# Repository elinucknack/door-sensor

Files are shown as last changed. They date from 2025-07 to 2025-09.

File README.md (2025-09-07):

# Door sensor

This is the documentation of Door sensor, an application that enables to create a door sensor from a Raspberry Pi. This door sensor can work offline or can be connected to an MQTT broker!

The following steps describe the installation of Door sensor on Raspberry Pi.

## Hardware build

The door sensor consists of a Raspberry Pi Zero 2 WH micro computer with additional electronic components allowing the micro computer to control the door sensor. Below, you can see the door sensor circuit schemes (also available in the `.kicad_sch` format):

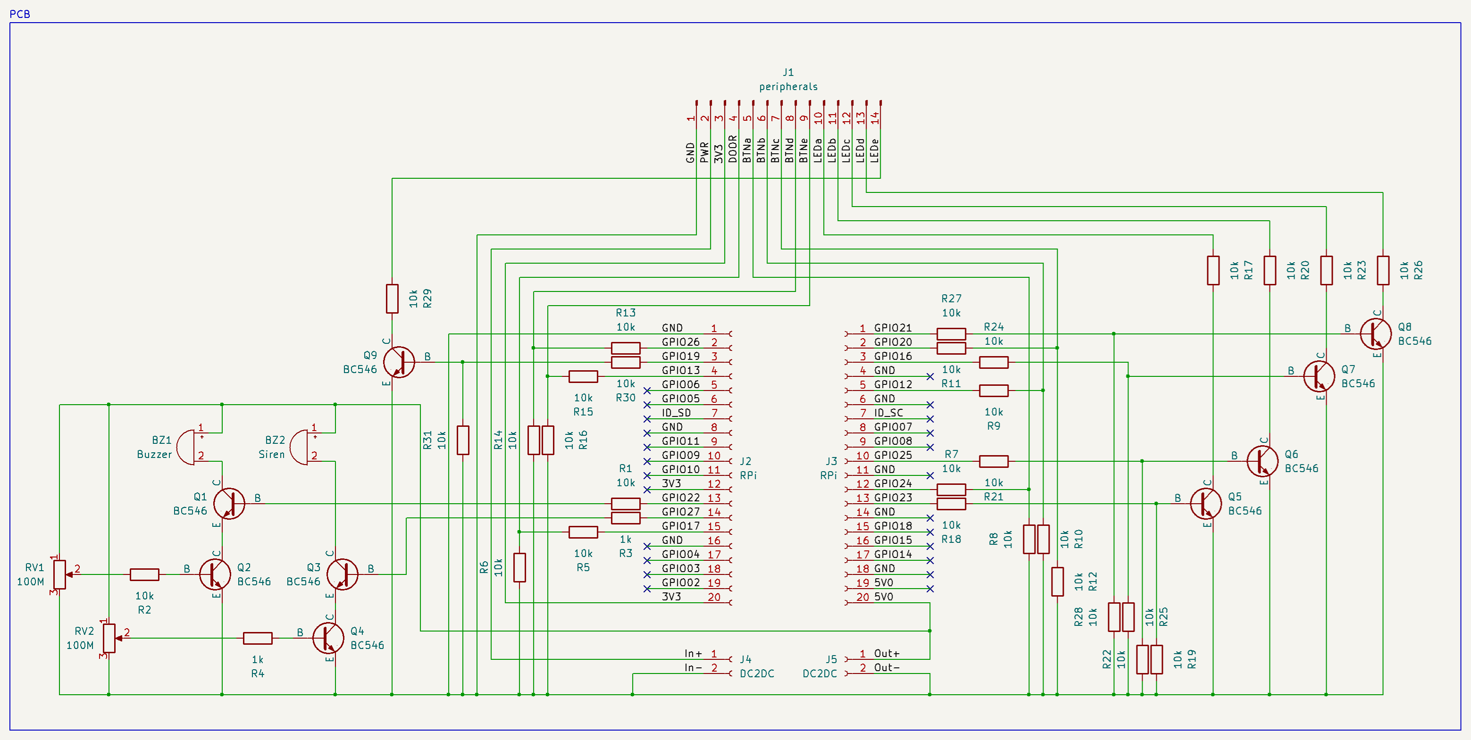
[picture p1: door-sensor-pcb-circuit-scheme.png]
Door sensor PCB circuit scheme


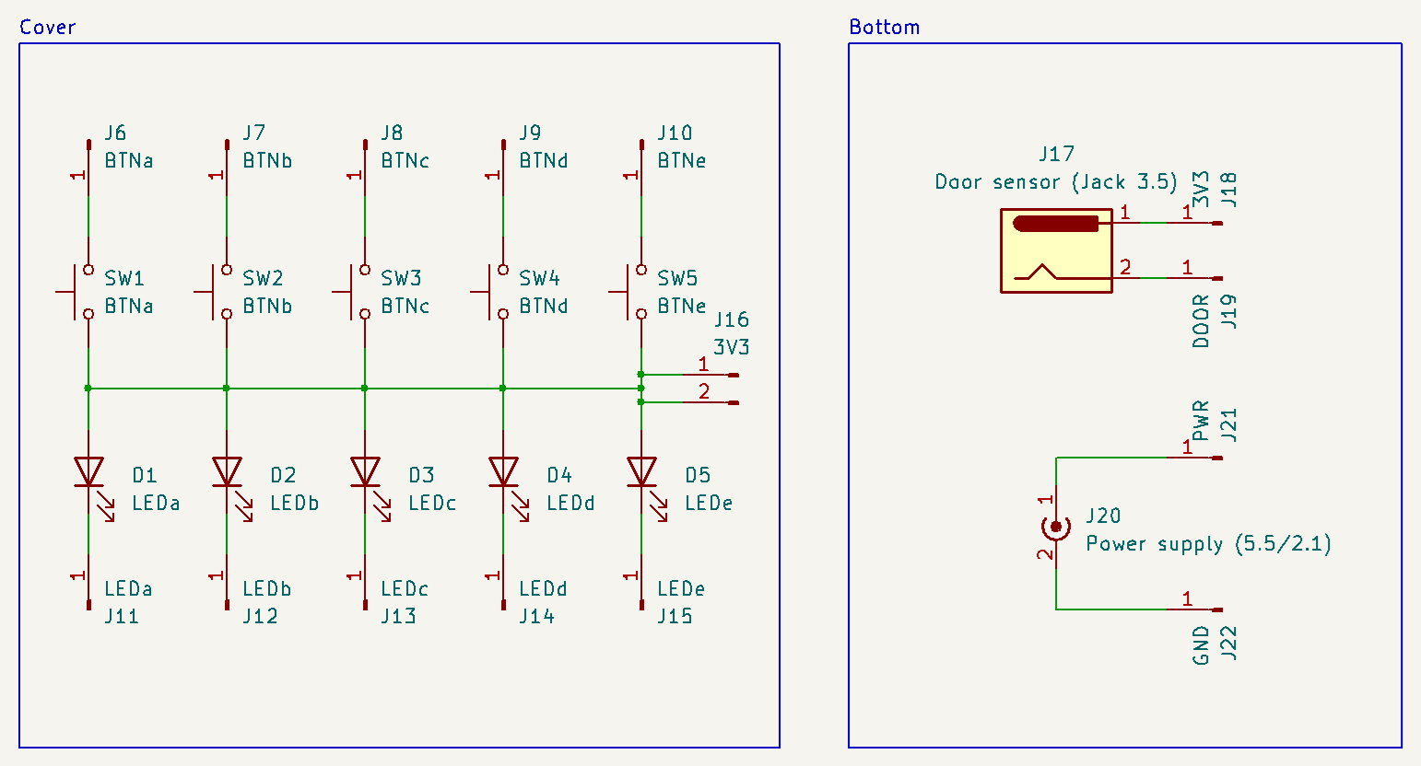
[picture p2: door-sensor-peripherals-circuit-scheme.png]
Door sensor peripherals circuit scheme


Below, you can see both sides of the door sensor PCB design (also available in the `.svg` format, the design uses an universal drilled PCB with 2.54mm hole pitch):

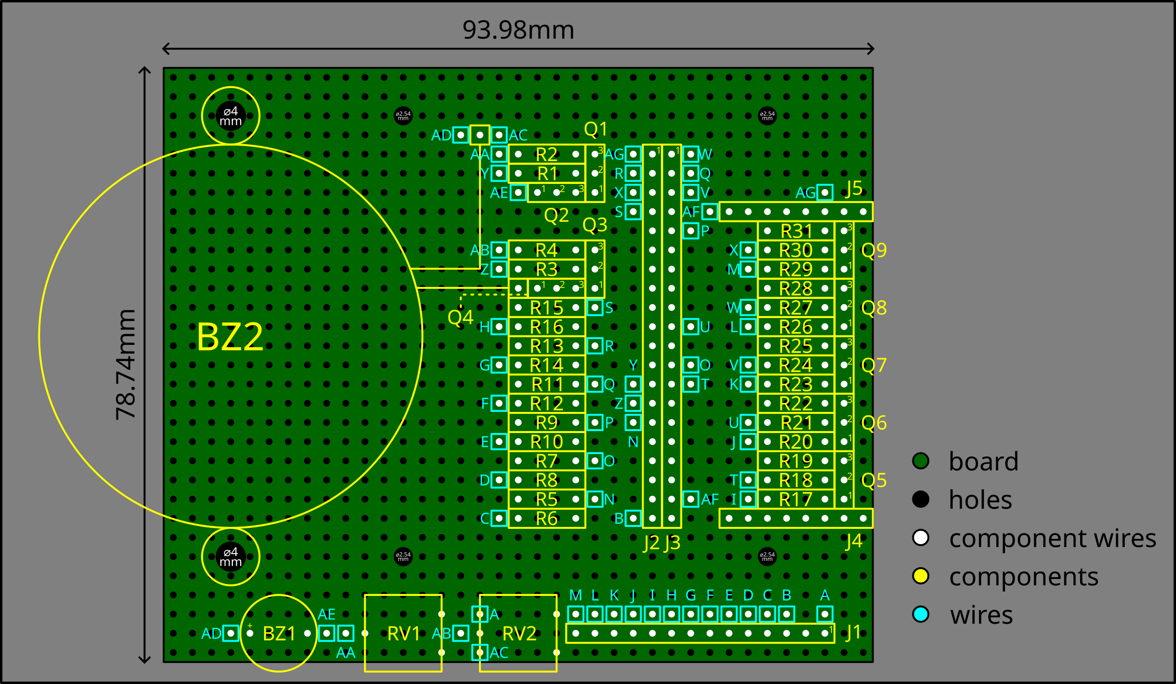
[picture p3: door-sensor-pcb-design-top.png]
PCB design - top side


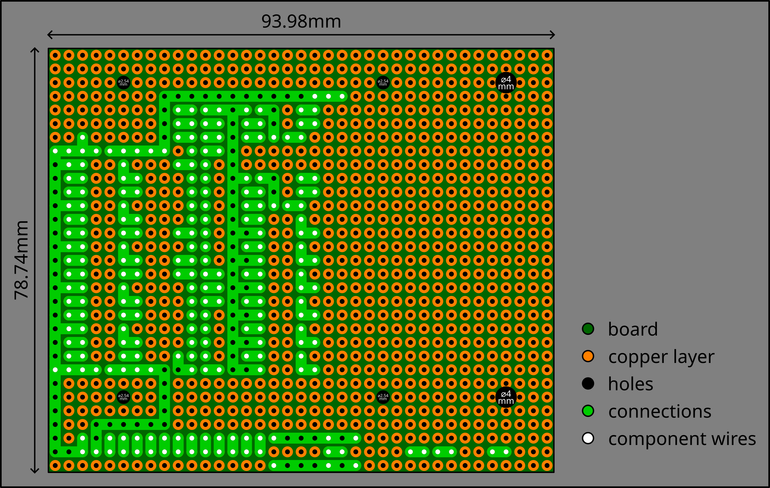
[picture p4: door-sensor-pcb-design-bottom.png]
PCB design - bottom side


The repository also includes printable 3D models (`.stl` files) of cases for the PCB. To mount the PCB to the case, you need 4 2.5×10mm screws. To assembly the case, you need 4 3.5×30mm screws. You also need 1 M4×30mm metric screw and 1 M4 nut in case you want to mount the camera holder. In case you don't want to edit the model, following components are recommended to be used if they are to fit into the holes in the PCB and in the case:
- KPEG242 as the buzzer `BZ1` ([link here](https://www.gmelectronic.com/v/1499434/kingstate-kpeg242-piezobuzzer))
- PS-583Q as the siren `BZ2` ([link here](https://www.gmelectronic.com/v/1498662/hitpoint-ps-583q-piezobuzzer), to mount the siren to the PCB, you need 2 M4×10mm metric screws and 2 M4 nuts)
- CA9VK100 as trimmers `RV1` and `RV2` ([link here](https://www.gmelectronic.com/v/1491831/acp-ca9vk100-carbon-trimmer))
- PBS-11B-R as buttons `SW1`, `SW2`, `SW3`, `SW4` and `SW5` ([link here](https://www.gmelectronic.com/v/1501016/pbs-11b-r-tlacitko-do-panelu-1-pol-offon))
- JC-204 as the Jack 3.5mm connector `J17` ([link here](https://www.gmelectronic.com/v/1497212/ninigi-jc-204-jack-35-mono))
- DS-026B as the power supply connector `J20` ([link here](https://www.gmelectronic.com/v/1498555/ds-026b-dc-connector-55-21))
- L-53LSRD as LEDs ([link here](https://www.gmelectronic.com/v/1491570/kingbright-l-53lsrd-led-5mm-cervena), regarding the required color and brightness, pick correspinding resistors `R17`, `R19`, `R21`, `R23` and `R25`)
- BL-C2 HR04C2 as LED sockets ([link here](https://www.gmelectronic.com/v/1492931/bright-led-bl-c2-hr04c2-objimka-pro-led-5mm))

Below, you can see an example of the built hardware:

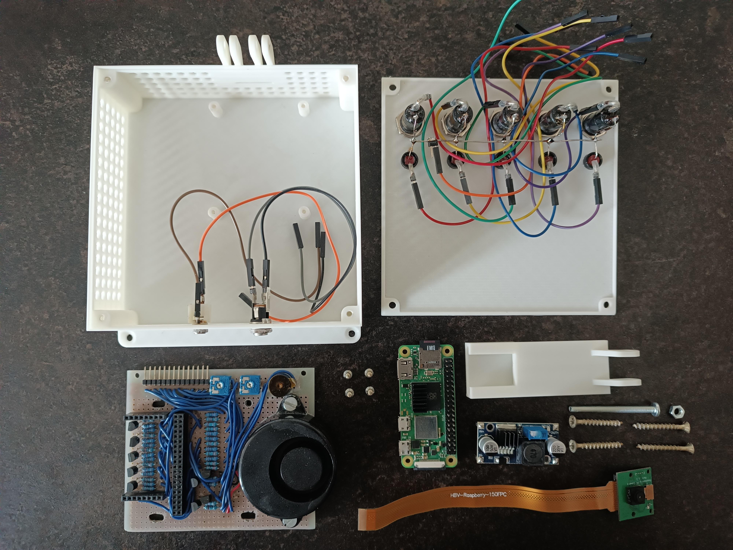
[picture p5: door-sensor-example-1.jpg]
Door sensor example 1


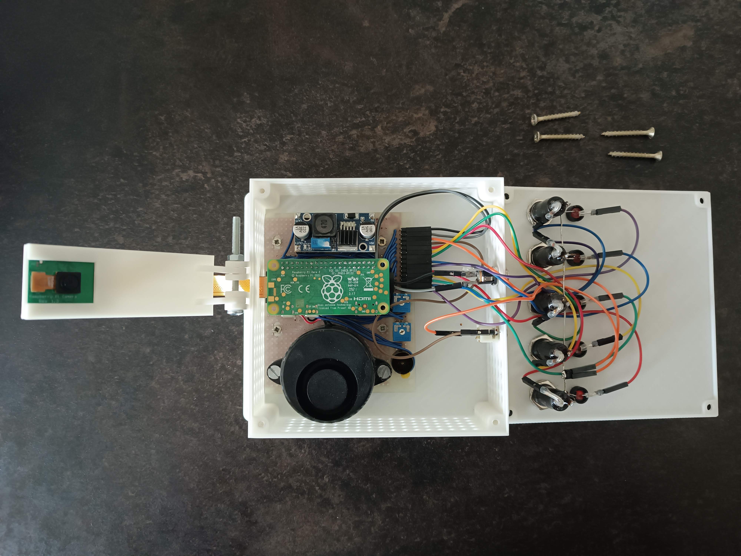
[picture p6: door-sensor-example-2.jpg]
Door sensor example 2


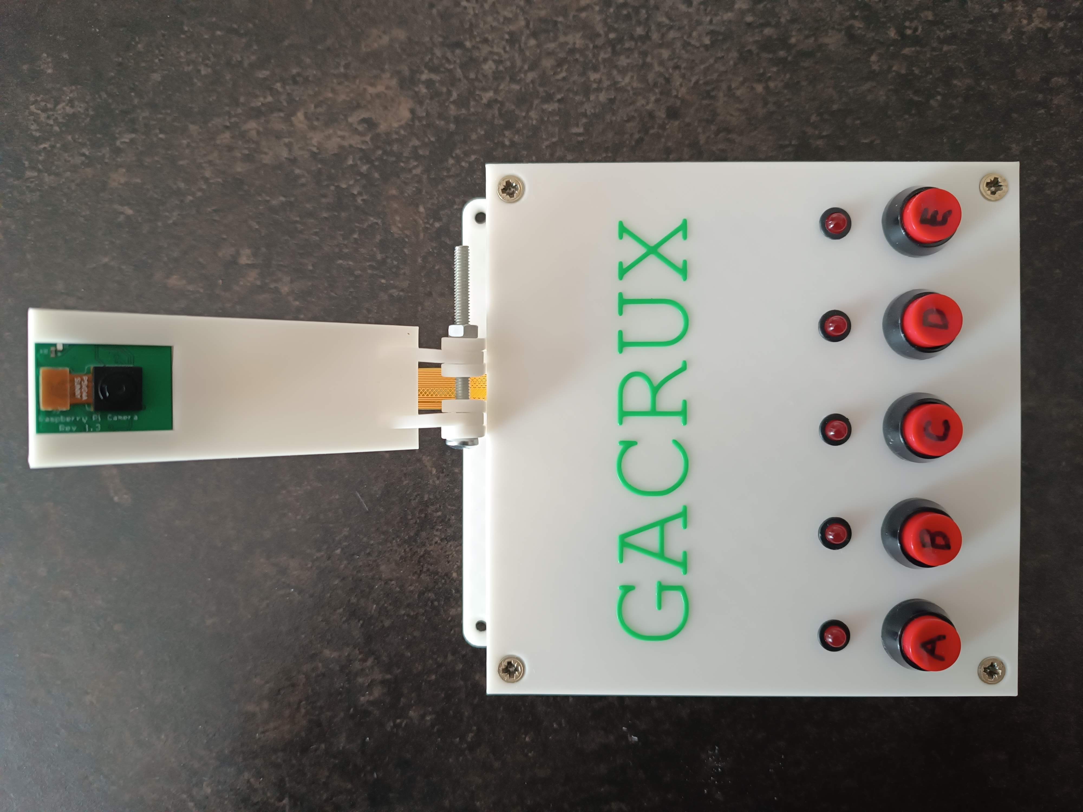
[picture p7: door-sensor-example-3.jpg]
Door sensor example 3


## Install the prerequisite software

### Install Node.js

1. Connect to the device through SSH.
2. Switch to `root` through `sudo su`.
3. Install Node.js and npm:
```
curl -sL https://deb.nodesource.com/setup_21.x | sudo bash -
apt update
apt upgrade
apt install nodejs
```

## Install the app

### Prepare the UNIX user

1. Connect to the device through SSH.
2. Switch to `root` through `sudo su`.
3. Create the new user `door-sensor`:
```
adduser door-sensor
```
4. Add user `door-sensor` to group `gpio`:
```
usermod -a -G gpio door-sensor
```

### Prepare the file system

1. Create the `/var/door-sensor` directory:
```
mkdir /var/door-sensor
chown door-sensor:door-sensor /var/door-sensor
```
2. Copy the content of this folder to the directory `/var/door-sensor`.

### Customize `door-sensor.service`

1. Set the environment variable `APP_MQTT_ENABLED` to `true` to enable the communication with an MQTT broker.
2. Depending on the configuration of MQTT broker, set `APP_MQTT_PROTOCOL` to `mqtt` or `mqtts`. In case of `mqtts`, it's necessary to put the certificate files into the directory `/var/door-sensor` and don't forget to set their filenames into `door-sensor.service`:
```
APP_MQTT_CA_FILENAME=rootCA.crt
APP_MQTT_CERT_FILENAME=mysite.crt
APP_MQTT_KEY_FILENAME=mysite.key
```
3. Set the MQTT broker password encoded in base64.
4. Depending on which pins the buttons, door sensor, signal diodes, beeper and siren are connected to, adjust the pin numbers in `door-sensor.service`.

### Install NPM modules and start the app

1. Install npm modules:
```
su - door-sensor
cd /var/door-sensor
npm install
exit
```
2. Enable and start the `door-sensor` service:
```
systemctl enable /var/door-sensor/door-sensor.service
systemctl start door-sensor
```

## RPi Camera integration

In case a Raspberry Pi Camera module v 1.3 is connected, it's also possible to use the device as a camera. In that case, follow the software installation instructions from the [RPi Camera repository](https://github.com/elinucknack/rpicamera).

### Usage

After the connection to the MQTT server, the door sensor sends its state every 15 seconds and after the state change using the `door-sensor-topic/state` topic, the `retain` flag is set to `true` and the `QoS` flag is set to `2`.

The door sensor state contains the following data:
- `notificationTrigger`: (ON/OFF)
- `sirenTrigger`: (ON/OFF)
- `siren`: (ON/OFF)
- `delayedSirenTriggerOn`: (ON/OFF)
- `delayedSirenOn`: (ON/OFF)
- `doorState`: (OPEN/CLOSE)
- `timestamp`: (Unix time in seconds)

You can enable the notification trigger using the `door-sensor-topic/notification-trigger-on` topic, set the `retain` flag to `false`.

You can disable the notification trigger using the `door-sensor-topic/notification-trigger-off` topic, set the `retain` flag to `false`.

You can enable the siren trigger using the `door-sensor-topic/siren-trigger-on` topic, set the `retain` flag to `false`.

You can disable the siren trigger using the `door-sensor-topic/siren-trigger-off` topic, set the `retain` flag to `false`.

You can switch off the siren using the `door-sensor-topic/siren-off` topic, set the `retain` flag to `false`.

## Authors

- [**Eli Nucknack**](mailto:eli.nucknack@gmail.com)

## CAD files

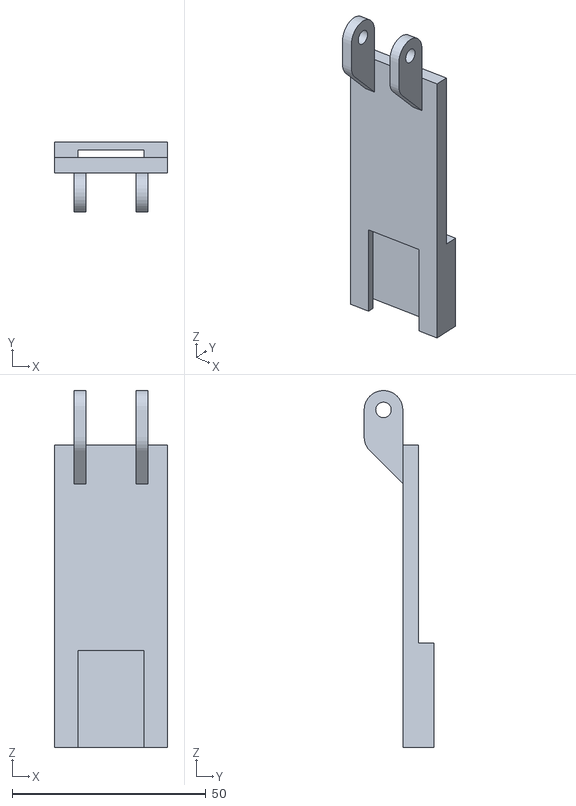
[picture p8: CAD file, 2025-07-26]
door-sensor-camera-holder-v2.stl
29.2 x 18.0 x 92.1

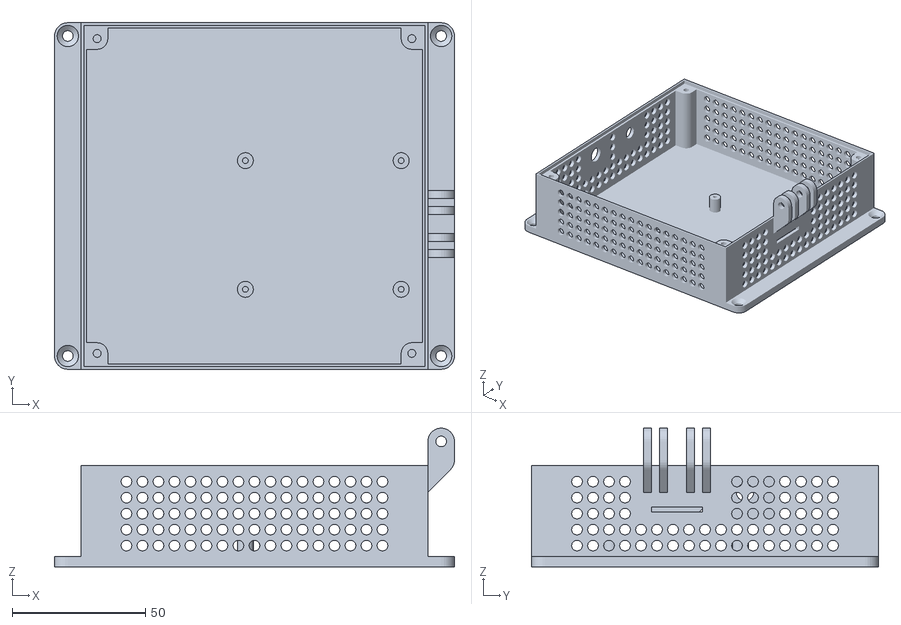
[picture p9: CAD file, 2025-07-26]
door-sensor-case-bottom-v2.stl
150.0 x 130.0 x 52.1

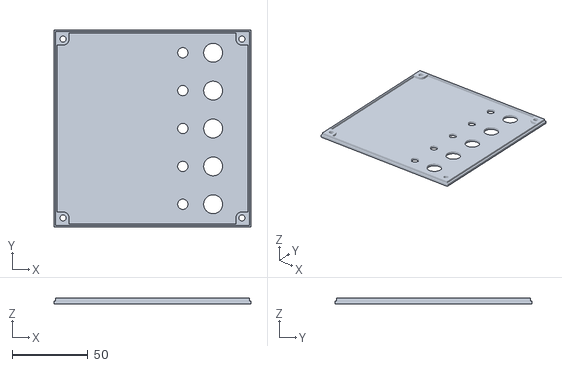
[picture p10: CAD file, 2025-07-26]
door-sensor-case-cover-v1-v2.stl
130.0 x 130.0 x 4.00

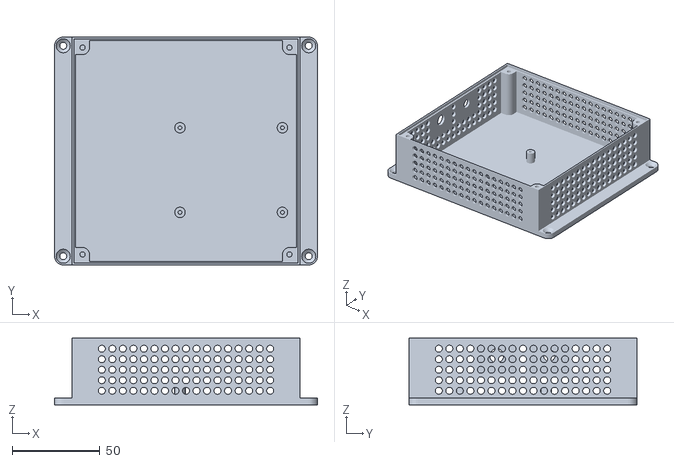
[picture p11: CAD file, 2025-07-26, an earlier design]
door-sensor-case-bottom-v1.stl
150.0 x 130.0 x 38.0

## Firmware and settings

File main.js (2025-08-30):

const winston = require('winston');

const logger = winston.createLogger({
    level: 'info',
    format: winston.format.combine(
        winston.format.timestamp({ format: 'YYYY-MM-DD HH:mm:ss' }),
        winston.format.printf(message => {
            const getLevel = message => `${message.exception ? 'UNCAUGHT EXCEPTION' : message.level.toUpperCase()}`;
            const getMessage = message => `${message.stack ? message.stack : message.message}${message.cause ? '\nCaused by ' + getMessage(message.cause) : ''}`;
            return `${message.timestamp} | ${getLevel(message)} | ${getMessage(message)}`;
        })
    ),
    transports: [
        new winston.transports.Console(),
        new winston.transports.File({
            filename: `${__dirname}/app.log`,
            maxsize: 1000000
        })
    ],
    exceptionHandlers: [
        new winston.transports.Console(),
        new winston.transports.File({
            filename: `${__dirname}/app.log`,
            maxsize: 1000000
        })
    ]
});

logger.info('=== DOOR SENSOR INITIALIZATION START ===');

logger.debug('Loading dependencies...');

const fs = require('fs');
const mqtt = require('mqtt');
const onoff = require('onoff');
const rxjs = require('rxjs');

logger.debug('Loading dependencies completed.');

logger.debug('Preparing output pin driver definition...');

const createOutputPinDriver = pinNumber => {
    const pin = new onoff.Gpio(pinNumber, 'low');
    
    let pulseTimeout = null;
    let pulseInterval = null;
    let pulseCount = null;
    
    let pulseTimeoutId = null;
    let pulseIntervalId = null;
    let remainingPulseCount = null;
    
    const setOn = () => {
        pulseTimeout = null;
        pulseInterval = null;
        pulseCount = null;
        
        clearTimeout(pulseTimeoutId);
        clearInterval(pulseIntervalId);
        pin.write(1);
    };
    
    const setOff = () => {
        pulseTimeout = null;
        pulseInterval = null;
        pulseCount = null;
        
        clearTimeout(pulseTimeoutId);
        clearInterval(pulseIntervalId);
        pin.write(0);
    };
    
    const pulse = (newPulseTimeout, newPulseInterval, newPulseCount) => {
        newPulseTimeout = newPulseTimeout || 50;
        newPulseInterval = newPulseInterval || 150;
        newPulseCount = newPulseCount || 1;
        
        if (pulseTimeout === newPulseTimeout && pulseInterval === newPulseInterval && pulseCount === newPulseCount && pulseCount === -1) {
            return;
        }
        
        pulseTimeout = newPulseTimeout;
        pulseInterval = newPulseInterval;
        pulseCount = newPulseCount;
        
        clearTimeout(pulseTimeoutId);
        clearInterval(pulseIntervalId);
        remainingPulseCount = pulseCount;
        
        const pulseOnceOrDie = () => {
            if (remainingPulseCount) {
                remainingPulseCount = remainingPulseCount === -1 ? -1 : remainingPulseCount - 1;
                pin.write(1);
                pulseTimeoutId = setTimeout(() => pin.write(0), pulseTimeout);
            } else {
                pulseTimeout = null;
                pulseInterval = null;
                pulseCount = null;
                
                clearInterval(pulseIntervalId);
            }
        };
        
        pulseOnceOrDie();
        pulseIntervalId = setInterval(pulseOnceOrDie, pulseInterval);
    };
    
    return {
        setOn: () => setOn(),
        setOff: () => setOff(),
        pulse: (pulseTimeout, pulseInterval, pulseCount) => pulse(pulseTimeout, pulseInterval, pulseCount)
    };
};

logger.debug('Preparing output pin driver definition completed.');

logger.debug('Creating output pin drivers...');

const notificationTriggerOffLedPinDriver = createOutputPinDriver(process.env.APP_NOTIFICATION_TRIGGER_OFF_LED_PIN);
const notificationTriggerOnLedPinDriver = createOutputPinDriver(process.env.APP_NOTIFICATION_TRIGGER_ON_LED_PIN);
const sirenTriggerOffLedPinDriver = createOutputPinDriver(process.env.APP_SIREN_TRIGGER_OFF_LED_PIN);
const sirenTriggerOnLedPinDriver = createOutputPinDriver(process.env.APP_SIREN_TRIGGER_ON_LED_PIN);
const sirenLedPinDriver = createOutputPinDriver(process.env.APP_SIREN_LED_PIN);
const buzzerPinDriver = createOutputPinDriver(process.env.APP_BUZZER_PIN);
const sirenPinDriver = createOutputPinDriver(process.env.APP_SIREN_PIN);

logger.debug('Creating output pin drivers completed.');

logger.debug('Preparing input pin driver definition...');

const createInputPinDriver = (pinNumber, throttleTime) => {
    const pin = new onoff.Gpio(pinNumber, 'in', 'both');
    const pinRising$ = new rxjs.BehaviorSubject(1);
    const pinFalling$ = new rxjs.BehaviorSubject(0);
    pin.watch((e, value) => {
        if (e) {
            throw e;
        }
        if (value) {
            pinRising$.next(value);
        } else {
            pinFalling$.next(value);
        }
    });
    const throttledPinRising$ = pinRising$.pipe(rxjs.skip(1), rxjs.throttleTime(throttleTime || 100));
    const throttledPinFalling$ = pinFalling$.pipe(rxjs.skip(1), rxjs.throttleTime(throttleTime || 100));
    
    return {
        get: () => pin.readSync(),
        watchRising: callback => throttledPinRising$.subscribe(callback || (value => {})),
        watchFalling: callback => throttledPinFalling$.subscribe(callback || (value => {}))
    };
};

logger.debug('Preparing input pin driver definition completed.');

logger.debug('Creating input pin drivers...');

const doorSensorPinDriver = createInputPinDriver(process.env.APP_DOOR_SENSOR_PIN, 100);
const notificationTriggerOffBtnPinDriver = createInputPinDriver(process.env.APP_NOTIFICATION_TRIGGER_OFF_BTN_PIN, 100);
const notificationTriggerOnBtnPinDriver = createInputPinDriver(process.env.APP_NOTIFICATION_TRIGGER_ON_BTN_PIN, 100);
const sirenTriggerOffBtnPinDriver = createInputPinDriver(process.env.APP_SIREN_TRIGGER_OFF_BTN_PIN, 100);
const sirenTriggerOnBtnPinDriver = createInputPinDriver(process.env.APP_SIREN_TRIGGER_ON_BTN_PIN, 100);
const sirenBtnPinDriver = createInputPinDriver(process.env.APP_SIREN_BTN_PIN, 100);

logger.debug('Creating input pin drivers completed.');

logger.debug('Preparing MQTT driver definition...');

const createMqttDriver = () => {
    let connection = null;
    
    const connect = () => {
        if (process.env.APP_MQTT_ENABLED === 'true') {
            let options = {
                protocol: process.env.APP_MQTT_PROTOCOL,
                host: process.env.APP_MQTT_HOST,
                port: process.env.APP_MQTT_PORT,
                username: process.env.APP_MQTT_USERNAME,
                password: Buffer.from(process.env.APP_MQTT_PASSWORD, 'base64').toString('utf8')
            };
            if (process.env.APP_MQTT_PROTOCOL === 'mqtts') {
                options = {
                    ...options,
                    ca: fs.readFileSync(`${__dirname}/${process.env.APP_MQTT_CA_FILENAME}`),
                    cert: fs.readFileSync(`${__dirname}/${process.env.APP_MQTT_CERT_FILENAME}`),
                    key: fs.readFileSync(`${__dirname}/${process.env.APP_MQTT_KEY_FILENAME}`)
                };
            }
            connection = mqtt.connect(options);
        } else {
            logger.warn('MQTT is disabled.');
        }
    };
    
    const publish = (topic, message, qos, retain) => {
        if (connection !== null) {
            connection.publish(
                `${process.env.APP_MQTT_TOPIC_SITE}/${process.env.APP_MQTT_TOPIC_DEVICE_TYPE}/${process.env.APP_MQTT_TOPIC_DEVICE_NAME}/${topic}`,
                message || '{}',
                { qos: qos || 0, retain: retain || false },
                e => {
                    if (e) {
                        logger.error(e);
                    }
                }
            );
        } else {
            logger.debug('MQTT is disabled, no data sent.');
        }
    };
    
    const subscribe = (topic, qos) => {
        if (connection !== null) {
            connection.subscribe(
                `${process.env.APP_MQTT_TOPIC_SITE}/${process.env.APP_MQTT_TOPIC_DEVICE_TYPE}/${process.env.APP_MQTT_TOPIC_DEVICE_NAME}/${topic}`,
                { qos: qos || 0 },
                e => {
                    if (e) {
                        logger.error(e);
                    }
                }
            );
        } else {
            logger.debug('MQTT is disabled, no subscription made.');
        }
    };
    
    const onConnect = callback => {
        if (connection !== null) {
            connection.on('connect', callback);
        }
    };
    
    const onClose = callback => {
        if (connection !== null) {
            connection.on('close', callback);
        }
    };
    
    const onError = callback => {
        if (connection !== null) {
            connection.on('error', callback);
        }
    };
    
    const onMessage = callback => {
        if (connection !== null) {
            connection.on('message', (topic, message) => {
                callback(
                    topic.substr(`${process.env.APP_MQTT_TOPIC_SITE}/${process.env.APP_MQTT_TOPIC_DEVICE_TYPE}/${process.env.APP_MQTT_TOPIC_DEVICE_NAME}/`.length),
                    message
                );
            });
        }
    };
    
    return {
        connect: () => connect(),
        publish: (topic, message, qos, retain) => publish(topic, message, qos, retain),
        subscribe: (topic, qos) => subscribe(topic, qos),
        onConnect: callback => onConnect(callback),
        onClose: callback => onClose(callback),
        onError: callback => onError(callback),
        onMessage: callback => onMessage(callback)
    };
};

logger.debug('Preparing MQTT driver definition completed.');

logger.debug('Creating MQTT driver...');

const mqttDriver = createMqttDriver();

logger.debug('Creating MQTT driver completed.');

logger.debug('Connecting MQTT server...');

mqttDriver.connect();

logger.debug('Connecting MQTT server completed.');

logger.debug('Preparing state driver definition...');

const createStateDriver = () => {
    let data = {
        notificationTrigger: 'OFF',
        sirenTrigger: 'OFF',
        siren: 'OFF',
        delayedSirenTriggerOn: 'OFF',
        delayedSirenOn: 'OFF',
        doorState: 'CLOSE'
    };
    
    const write = callback => {
        fs.writeFile(`${__dirname}/state.json`, JSON.stringify({
            notificationTrigger: data.notificationTrigger,
            sirenTrigger: data.sirenTrigger
        }, null, '    '), e => {
            if (e) {
                logger.error(e);
            } else {
                (callback || (() => {}))();
            }
        });
    };
    
    const read = () => {
        if (!fs.existsSync(`${__dirname}/state.json`)) {
            write(() => logger.warn('State file does not exist. New state file created.'));
            mqttDriver.publish('state', JSON.stringify({ ...data, timestamp: Date.now() }, null, '    '), 2, true);
        } else {
            try {
                data = { ...data, ...JSON.parse(fs.readFileSync(`${__dirname}/state.json`, 'utf8')) };
                data = { ...data, doorState: doorSensorPinDriver.get() ? 'CLOSE' : 'OPEN' };
            } catch (e) {
                write(() => logger.warn('Invalid state file content. New state file created.'));
                mqttDriver.publish('state', JSON.stringify({ ...data, timestamp: Date.now() }, null, '    '), 2, true);
            }
        }
    };
    
    const apply = (buzzerPulseTimeout, buzzerPulseInterval, buzzerPulseCount) => {
        if (data.notificationTrigger === 'OFF') {
            notificationTriggerOffLedPinDriver.setOn();
        } else {
            notificationTriggerOffLedPinDriver.setOff();
        }
        
        if (data.notificationTrigger === 'ON') {
            notificationTriggerOnLedPinDriver.setOn();
        } else {
            notificationTriggerOnLedPinDriver.setOff();
        }
        
        if (data.sirenTrigger === 'OFF') {
            sirenTriggerOffLedPinDriver.setOn();
        } else {
            sirenTriggerOffLedPinDriver.setOff();
        }
        
        if (data.sirenTrigger === 'ON') {
            sirenTriggerOnLedPinDriver.setOn();
        } else if (data.delayedSirenTriggerOn === 'ON') {
            sirenTriggerOnLedPinDriver.pulse(250, 500, -1);
        } else {
            sirenTriggerOnLedPinDriver.setOff();
        }
        
        if (data.siren === 'ON') {
            sirenLedPinDriver.setOn();
        } else if (data.delayedSirenOn === 'ON') {
            sirenLedPinDriver.pulse(250, 500, -1);
        } else {
            sirenLedPinDriver.setOff();
        }
        
        if (data.delayedSirenTriggerOn === 'ON') {
            buzzerPinDriver.pulse(25, 1000, -1);
        } else if (buzzerPulseCount) {
            buzzerPinDriver.pulse(buzzerPulseTimeout, buzzerPulseInterval, buzzerPulseCount);
        } else {
            buzzerPinDriver.setOff();
        }
        
        if (data.siren === 'ON') {
            sirenPinDriver.setOn();
        } else {
            sirenPinDriver.setOff();
        }
    };
    
    const getAll = () => {
        return data;
    };
    
    const get = prop => {
        return data[prop];
    };
    
    let delayedSirenTriggerOnTimeoutId = null;
    let delayedSirenOnTimeoutId = null;
    
    const set = (newData, buzzerPulseTimeout, buzzerPulseInterval, buzzerPulseCount) => {
        newData = newData || {};
        data = { ...data, ...newData };
        if (newData.delayedSirenTriggerOn === 'ON') {
            clearTimeout(delayedSirenTriggerOnTimeoutId);
            delayedSirenTriggerOnTimeoutId = setTimeout(() => {
                set({ sirenTrigger: 'ON', delayedSirenTriggerOn: 'OFF' }, 25, 150, 3);
            }, process.env.APP_SIREN_TRIGGER_ON_DELAY * 1000);
        }
        if (newData.delayedSirenTriggerOn === 'OFF') {
            clearTimeout(delayedSirenTriggerOnTimeoutId);
        }
        if (newData.delayedSirenOn === 'ON') {
            clearTimeout(delayedSirenOnTimeoutId);
            delayedSirenOnTimeoutId = setTimeout(() => {
                set({ siren: 'ON', delayedSirenOn: 'OFF' });
            }, process.env.APP_SIREN_ON_DELAY * 1000);
        }
        if (newData.delayedSirenOn === 'OFF') {
            clearTimeout(delayedSirenOnTimeoutId);
        }
        write();
        mqttDriver.publish('state', JSON.stringify({ ...data, timestamp: Date.now() }, null, '    '), 2, true);
        apply(buzzerPulseTimeout, buzzerPulseInterval, buzzerPulseCount);
    };
    
    return {
        read: () => read(),
        apply: (buzzerPulseTimeout, buzzerPulseInterval, buzzerPulseCount) => apply(buzzerPulseTimeout, buzzerPulseInterval, buzzerPulseCount),
        getAll: () => getAll(),
        get: prop => get(prop),
        set: (newData, buzzerPulseTimeout, buzzerPulseInterval, buzzerPulseCount) => set(newData, buzzerPulseTimeout, buzzerPulseInterval, buzzerPulseCount)
    };
};

logger.debug('Preparing state driver definition completed.');

logger.debug('Creating state driver...');

const stateDriver = createStateDriver();

logger.debug('Creating state driver completed.');

logger.debug('Initiating state...');

stateDriver.read();
stateDriver.apply();

logger.debug('Initiating state completed.');

logger.debug('Creating input pin listeners...');

doorSensorPinDriver.watchRising(value => {
    stateDriver.set({ doorState: 'CLOSE' });
});

doorSensorPinDriver.watchFalling(value => {
    let newData = { doorState: 'OPEN' };
    if (stateDriver.get('sirenTrigger') === 'ON' && stateDriver.get('delayedSirenOn') === 'OFF' && stateDriver.get('siren') === 'OFF') {
        newData = { ...newData, delayedSirenOn: 'ON' };
    }
    stateDriver.set(newData);
    if (stateDriver.get('notificationTrigger') === 'ON') {
        mqttDriver.publish('door-open', '{}', 2);
    }
});

notificationTriggerOffBtnPinDriver.watchRising(value => {
    if (stateDriver.get('notificationTrigger') === 'ON') {
        stateDriver.set({ notificationTrigger: 'OFF' }, 25, 150, 1);
    }
});

notificationTriggerOnBtnPinDriver.watchRising(value => {
    if (stateDriver.get('notificationTrigger') === 'OFF') {
        stateDriver.set({ notificationTrigger: 'ON' }, 25, 150, 1);
    }
});

sirenTriggerOffBtnPinDriver.watchRising(value => {
    if (stateDriver.get('sirenTrigger') === 'ON' || stateDriver.get('delayedSirenTriggerOn') === 'ON') {
        stateDriver.set({ sirenTrigger: 'OFF', delayedSirenTriggerOn: 'OFF' }, 25, 150, 1);
    }
});

sirenTriggerOnBtnPinDriver.watchRising(value => {
    if (stateDriver.get('sirenTrigger') === 'OFF' && stateDriver.get('delayedSirenTriggerOn') === 'OFF') {
        stateDriver.set({ delayedSirenTriggerOn: 'ON' });
    }
});

sirenBtnPinDriver.watchRising(value => {
    if (stateDriver.get('delayedSirenOn') === 'ON' || stateDriver.get('siren') === 'ON') {
        stateDriver.set({ delayedSirenOn: 'OFF', siren: 'OFF' }, 25, 150, 1);
    }
});

logger.debug('Creating input pin listeners completed.');

logger.debug('Creating MQTT listeners...');

let connectionState = 'unknown';

const setConnectionState = newConnectionState => {
    connectionState = newConnectionState;
    logger.info(`MQTT client ${newConnectionState}.`);
    if (['connected', 'reconnected'].includes(newConnectionState)) {
        mqttDriver.publish('state', JSON.stringify({ ...stateDriver.getAll(), timestamp: Date.now() } , null, '    '), 2, true);
    }
};

mqttDriver.onConnect(() => {
    if (['unknown', 'unconnected'].includes(connectionState)) {
        setConnectionState('connected');
    } else if (connectionState === 'disconnected') {
        setConnectionState('reconnected');
    }
});

mqttDriver.onClose(() => {
    if (connectionState === 'unknown') {
        setConnectionState('unconnected');
    } else if (['connected', 'reconnected'].includes(connectionState)) {
        setConnectionState('disconnected');
    }
});

mqttDriver.subscribe('#', 2);
mqttDriver.onMessage((topic, message) => {
    switch (topic) {
        case 'notification-trigger-off':
            if (stateDriver.get('notificationTrigger') === 'ON') {
                stateDriver.set({ notificationTrigger: 'OFF' }, 25, 150, 1);
            }
            break;
        case 'notification-trigger-on':
            if (stateDriver.get('notificationTrigger') === 'OFF') {
                stateDriver.set({ notificationTrigger: 'ON' }, 25, 150, 1);
            }
            break;
        case 'siren-trigger-off':
            if (stateDriver.get('sirenTrigger') === 'ON' || stateDriver.get('delayedSirenTriggerOn') === 'ON') {
                stateDriver.set({ sirenTrigger: 'OFF', delayedSirenTriggerOn: 'OFF' }, 25, 150, 1);
            }
            break;
        case 'siren-trigger-on':
            if (stateDriver.get('sirenTrigger') === 'OFF') {
                stateDriver.set({ sirenTrigger: 'ON', delayedSirenTriggerOn: 'OFF' }, 25, 150, 3);
            }
            break;
        case 'siren-off':
            if (stateDriver.get('delayedSirenOn') === 'ON' || stateDriver.get('siren') === 'ON') {
                stateDriver.set({ delayedSirenOn: 'OFF', siren: 'OFF' }, 25, 150, 1);
            }
            break;
        default:
    }
});

logger.debug('Creating MQTT listeners completed.');

logger.debug('Creating door sensor state repeater...');

setInterval(() => {
    stateDriver.set({ doorState: doorSensorPinDriver.get() ? 'CLOSE' : 'OPEN' });
}, 15000);

logger.debug('Creating door sensor state repeater completed.');

logger.info('=== DOOR SENSOR INITIALIZATION COMPLETED ===');

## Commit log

2025-07-26 Documentation enhancement
    [door-sensor-camera-holder-v2.stl, door-sensor-case-bottom-v1.stl, door-sensor-case-bottom-v2.stl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]
2025-08-03 Door sensor documentation update
    [door-sensor-pcb.kicad_sch]
2025-08-03 PCB design enhanced
